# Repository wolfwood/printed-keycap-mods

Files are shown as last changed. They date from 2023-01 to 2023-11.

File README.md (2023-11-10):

# Print Keycaps That Feel Great
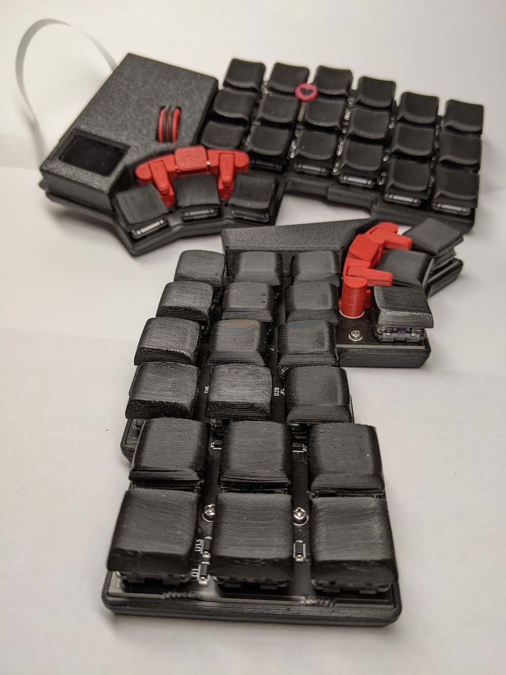
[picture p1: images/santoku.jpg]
Santoku Keyboard from Gestalt Input


This code modifies and positions open source, 3D printable key caps, such as Chicago Steno, for printing, using Lev Popov's suggestions for FDM printing keycaps in [the LPX repo](https://github.com/levpopov/LPX) and in [his printables for Chicago Steno](https://www.printables.com/model/158865-chicago-steno-low-profile-keycaps-kailh-choc).

## Modify Keycaps to Fit Around Trackpoint
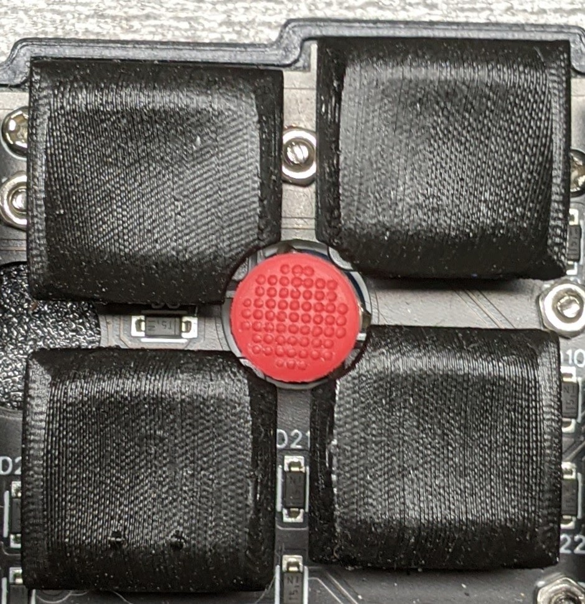
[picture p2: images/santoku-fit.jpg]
Chicago Steno around a Santoku trackpoint


This code also takes keycaps and cuts notches to make room for a trackpoint's rubber dome. No need to grind them down. It does this for the Santoku keyboard (pictured above), a tryadactyl with cylindrical placement, or ortholinear keyboards with MX or choc spacing. However, it can be easily modified to accommodate any keyboard layout.

### Placement
Two trackpoint placements are supported. The upper left corner of the home key, "index" or *index=true*, and the upper right corner of the home key, "middle" or *index=false*.

## Stupid Stem Tricks
For non-SCAD keycaps we can easily remove the stem using a `difference()` and replace it with whatever we like. This opens several possibilities. For SCAD keycaps we can likely tweak the source, or pass appropriate parameters.

### MX Stem Swap
The LPxMX profile is a choc keycap on an MX stem from @rsheldiii's [keyV2 library](https://github.com/rsheldiii/KeyV2.git) which was designed to be amenable to FDM printing.

### Stem Offsets
For dactyls using a typical cylindrical column placement, there is no issue with the keyswitches colliding. However, if we try to have a convex portion of our column (such as for the number row) the keycaps may be spaced far enough apart that the switches below would collide. Using an offset stem allows us to pack keycaps more tightly, while spacing the switches far enough apart that they don't intersect.

Currently only implemented for LPX.

# Profiles
### [LPX](https://github.com/levpopov/LPX)
No unmodified keycap is generated. Use [the source *.stl* file](https://github.com/levpopov/LPX/blob/main/LPX.stl).

Since LPX is a symmetrical, non-sculpted profile, right now only two trackpoint-modded keycaps are generated. Support for a homing key could be added.

### [Chicago Steno](https://github.com/pseudoku/PseudoMakeMeKeyCapProfiles)
A full set of keycaps can be rendered for printing.

For trackpoint use, an array of 4 keycaps is rendered (or optionally, files for individual keycaps), with the appropriate notches depending on *index* or *middle* placement. The keycaps are R3 homing, R3 and two R2s (near and far).

Chicago Steno from @pseudoku is made available under the GPL v3 and the optional (off by default) prerenders from @levpopov are CC BY-NC-SA 4.0.

# Usage
This repository relies on submodules to include keycaps where possible. Either clone it with the command `git clone --recurse-submodules --remote-submodules` to automatically fetch submodules, or run `git submodule update --init --recursive` in an already cloned repo before using.

Keycaps can be rendered using `make`. first edit `settings.scad` to set the keyboard, and optionally the grid spacing (only used by Chicago Steno for now). If run without arguments, `make` will render all profiles and positions for a given board. To save render time you can invoke a specific target such as `make lpx` or `make cs-middle`. A set of unmodified Chicago Steno keycaps can be generated with `make cs`. The targets `cs-middle-solo` and `cs-index-solo` generate modified keycaps in individual *.stl*s rather than arrays.

I strongly recommend downloading [a development snapshot of OpenSCAD](https://openscad.org/downloads.html#snapshots) and replacing the `OPENSCAD=openscad` line at the begining of the Makefile with the path to the downloaded build (don't forget to `chmod +x` it first, if using an AppImage), so that you can enable the `manifold` feature. I currently use `OPENSCAD=$(HOME)/downloads/OpenSCAD-2023.11.08.ai16933-x86_64.AppImage --enable=manifold --enable=predictible-output` (predictible-output will probably be slower, but it's useful for detecting changes).

# FDM Printing Suggestions
Parts are positioned with a 45 degree Y and Z rotation. These recommendations come from @levpopov. The Y rotation produces a smoother surface than printing flat. The Z rotation slows the print head and gets maximum cooling on the top surface.

If using a keycap array *.stl*, split the model to objects in your slicer, then enable *complete individual objects*.

The main issue I've had has been with the bottom edge of the keycap partially or full detaching during the print. The support tweaks are meant to address this issue, along with the model modifications to flatten the edges the keycap rests on while printing.

  - *layer height* - On the Prusa MK3S I used 0.1 mm. 0.07 mm is doable but arguably feels worse. 0.15 is acceptable and definitely where you should start your testing before trying to print multiple keycaps. On the Prusa MK4 I was able to use .05 mm with a brim which produced a very smooth top surface, but also a rough patch on one edge.
  - *0% infill* - This helps with surface smoothness. also faster.
  - *enable supports* - This thing is gonna tip over if you don't support it! I have preferred to use traditional supports. Tree supports are definitely not effective without a brim; the whole model benefits from a solid support structure. As of prusaslice 2.6, the default is support style is snug, which applies the following by default.
	- *Top contact Z distance* = 0.10 - get supports closer to the part
    - *Pattern spacing* = 1.5 - more supportive
  - *Complete individual objects* - prints parts one at a time so there isn't stringing between keycaps ruining the top surface. you also need to split models with multiple keycaps, if using.

# SLA Printing Suggestions
??? Someone with a resin printer please tell us.

# Suggestions Welcome!
Please open an issue to request support for new keycaps, new keyboards, flexibility in selecting row variants, etc. I'd like to expand this tool to accommodate as many uses as possible.

# TODO
  - [x] fix orientation of 'from source' CS keycaps
  - [x] check if LPX needs 2 different notches now that santoku offset is corrected
  - [ ] reorg related keycap code into directories
  - [ ] means to specify arbitrary arrays of keycaps (in settings/from render command)
    - [ ] split array generation off from main keycap files (can be generic? or per-profile?)
  - [x] means to generate individual trackpoint notched keycaps, not in an array
    - [x] communicate trackpoint notch location in a more clear and universal manner
  - [ ] way to add sprues to keycap arrays for commercial 3D printing? what about shrinkage?
  - [ ] stem mods, such as integrated tilters
	- [x] LPxMX
    - [x] LPX-offset
    - [ ] CS-MX
    - [ ] longer LPX stem for damper?
  - [ ] try out more keycaps from https://github.com/namnlos-io/choc_keycaps
  - [ ] https://github.com/madebyperce/shelby-min-mx-keycaps LPxMX alternative?
  - [ ] support more keycaps from keyV2? rewrite this code a branch of keyV2?
  - [ ] CS T1S
  - [ ] bigger homing dots?
  - [ ] makefile rules to fetch submodules if missing

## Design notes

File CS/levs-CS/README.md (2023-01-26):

# Chicago Steno *.stl*s

[Chicago Steno models](https://github.com/pseudoku/PseudoMakeMeKeyCapProfiles) by way of Lev Popov's [guide for FDM printed keycaps](https://www.printables.com/model/158865-chicago-steno-low-profile-ergo-keycaps).

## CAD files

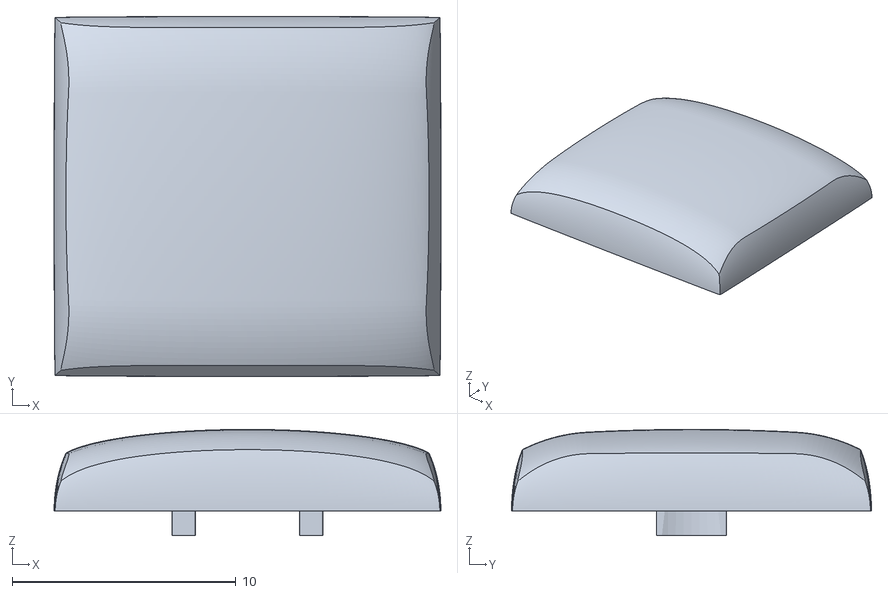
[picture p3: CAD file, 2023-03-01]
CS/levs-CS/convex-1u-for-thumbs-or-inner-index-column.stl
17.3 x 16.1 x 4.75

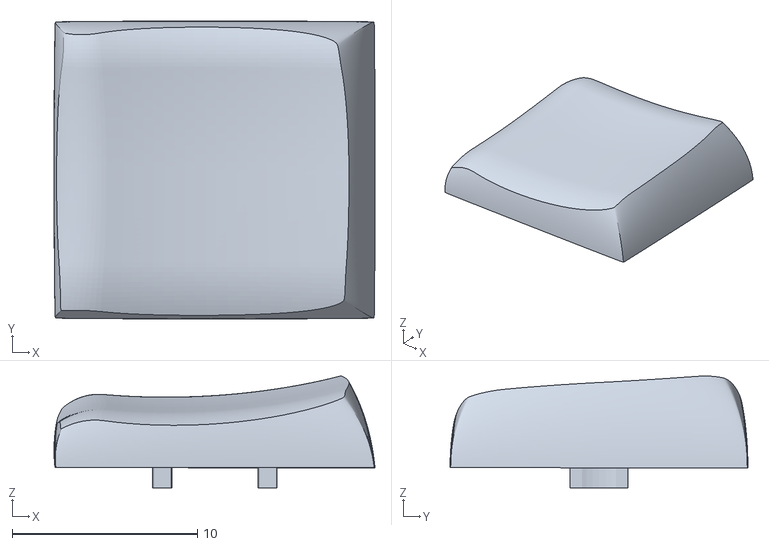
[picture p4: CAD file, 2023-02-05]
CS/levs-CS/thumb-1u.stl
17.4 x 16.1 x 6.05

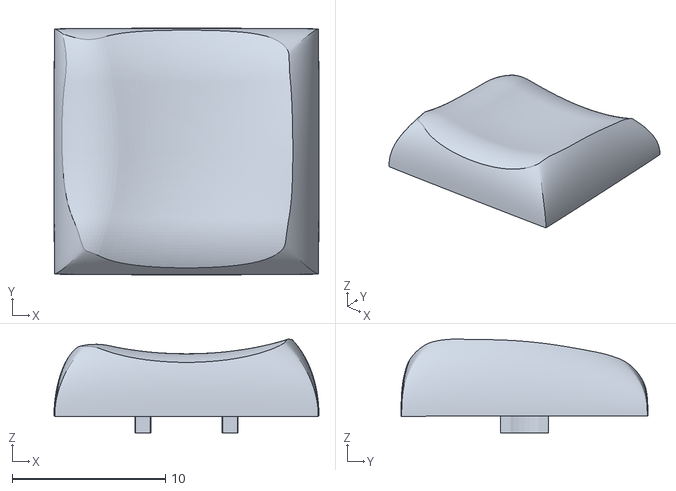
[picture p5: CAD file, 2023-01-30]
CS/levs-CS/r2r4L-side-columns.stl
17.3 x 16.1 x 6.12

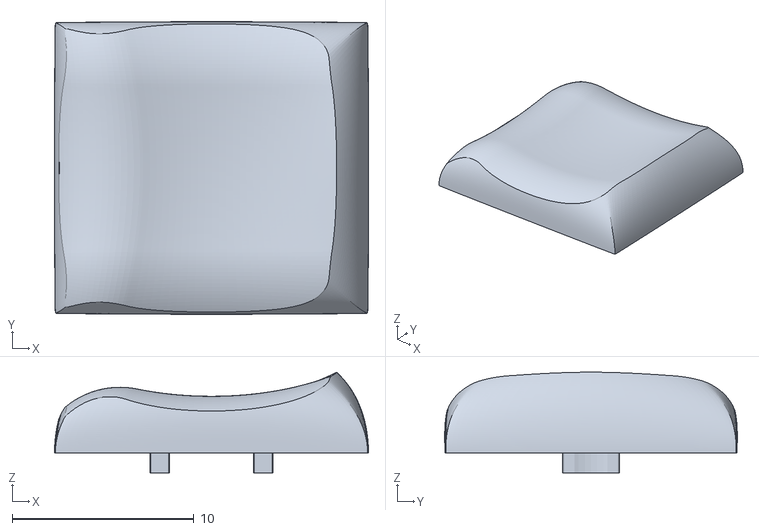
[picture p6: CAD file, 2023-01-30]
CS/levs-CS/r3L-side-columns.stl
17.3 x 16.1 x 5.55

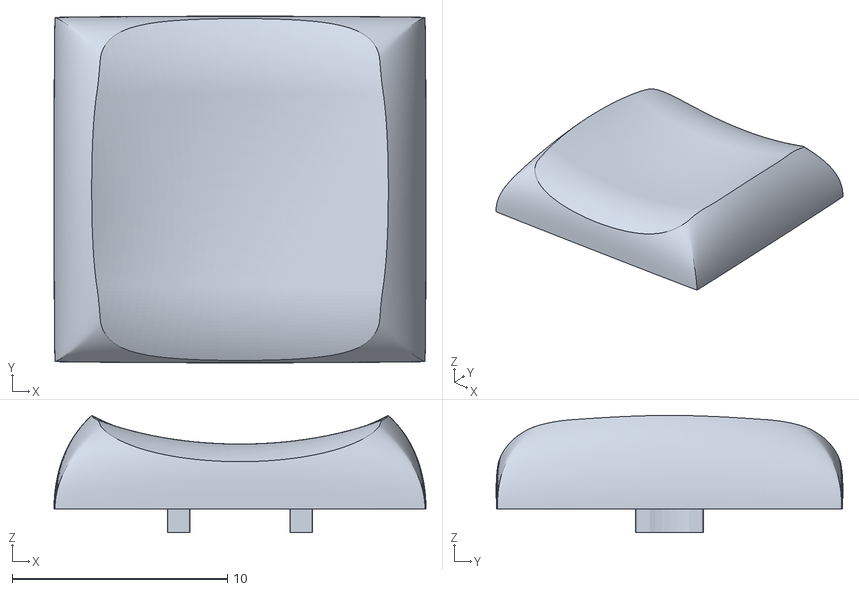
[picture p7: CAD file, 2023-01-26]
CS/levs-CS/r3-middle-row.stl
17.3 x 16.1 x 5.45

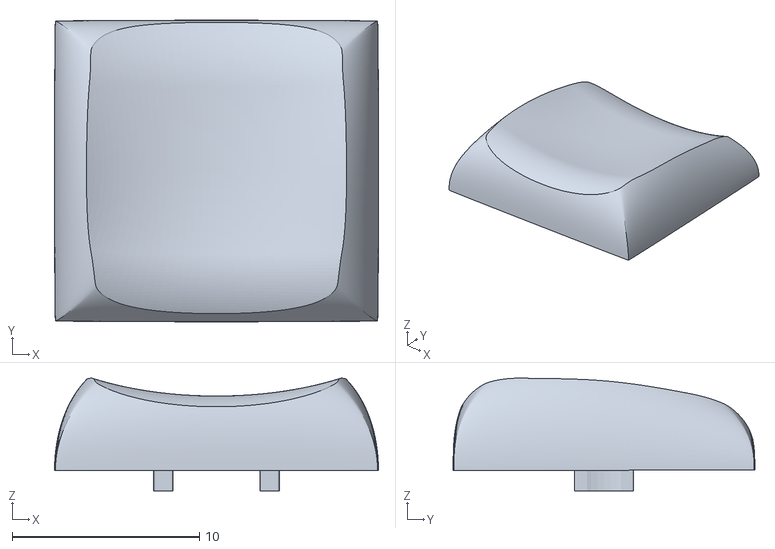
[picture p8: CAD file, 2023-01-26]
CS/levs-CS/r2r4-topbottom-rows.stl
17.3 x 16.1 x 6.02

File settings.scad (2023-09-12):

keyboard = "santoku";

grid_spacing = [54,66];
grid_stagger = true;


// original code was for a prusa MK3 with the print cooling fan duct on the right of the extruder
// MK4 has fan ducts on the left (and front)
fans_on_left=true;


// use a chamfered notch rather than a hole that accommodates the entire trackpoint cap
// chamfer makes a lot of polygons and can fail to preview / consume a lot of RAM and CPU when rendering
function tp_chamfer() = $preview ? false : true;

// less than .05 requires more than 8 GB of RAM if rendered in the gui
// not sure if there's a size that lets previews work
function tp_chamfer_steps() = .05;

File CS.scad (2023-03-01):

include <util.scad>;
include <trackpoint_notch.scad>;
include <settings.scad>;

use <CS-bindings/sculpted.scad>;
use <CS-bindings/thumb.scad>;
use <CS-bindings/convex.scad>;

prerendered=false;

module CS(type="R3") {
  if (prerendered) {
    CS_prerendered(type);
  } else {
    CS_from_source(type);
  }
}

module CS_from_source(type="R3") {
  $fn=60;

  if (type == "R3") {
    sculpted_key(type);
  } else if (type == "R3-homing") {
    sculpted_key("R3", homing=true);
  } else if (type == "R2") {
    mirror([0,1,0]) sculpted_key("R4");
  } else if (type == "R4") {
    sculpted_key(type);
  } else if (type == "R2L" || type == "R4R") {
    mirror([1,0,0]) thumb_key("R2L");
  } else if (type == "R3L" || type == "R3R") {
    // smoother feel if you don't print with the curved side at the top
    rotate([0,0,180]) thumb_key("R3L");
  } else if (type == "R4L" || type == "R2R") {
    // smoother feel if you don't print with the curved side at the top
    rotate([0,0,180]) thumb_key("R2L");
  } else if (type == "T1L") {
    // smoother feel if you don't print with the curved side at the top
    rotate([0,0,180]) thumb_key("T1");
  } else if (type == "T1R") {
    mirror([1,0,0]) thumb_key("T1");
  } else if (type == "R3x") {
    convex_key(type);
  } else {
    assert(false, str("unrecognized Chicago Steno keycap type: ", type));
  }
}

module CS_prerendered(type="R3") {
  if (type == "R3") {
    import("levs-CS/r3-middle-row.stl");
  } else if (type == "R3-homing") {
    import("levs-CS/r3-homing.stl");
  } else if (type == "R2") {
    rotate([0,0, 180]) import("levs-CS/r2r4-topbottom-rows.stl");
  } else if (type == "R4") {
    import("levs-CS/r2r4-topbottom-rows.stl");
  } else if (type == "R2L" || type == "R4R") {
    import("levs-CS/r2r4L-side-columns.stl");
  } else if (type == "R3L" || type == "R3R") {
    //rotate([0,0, 180])
      import("levs-CS/r3L-side-columns.stl");
  } else if (type == "R4L" || type == "R2R") {
    mirror([0,1,0]) import("levs-CS/r2r4L-side-columns.stl");
  } else if (type == "T1L") {
    rotate([0,0,180])
      mirror([1,0,0]) import("levs-CS/thumb-1u.stl");
  } else if (type == "T1R") {
    import("levs-CS/thumb-1u.stl");
  } else if (type == "R3x") {
    import("levs-CS/convex-1u-for-thumbs-or-inner-index-column.stl");
  } else {
    assert(false, str("unrecognized Chicago Steno keycap type: ", type));
  }
}

module printable(other=false) {
  difference(){
    rotate([0,0,other ? -45 : 135])
      rotate([0,(other ? 1 : -1)*45,0]) children();

    // nip off the edge so the keycap sticks better to the print bed
    h=5;
    cut_distance=4.9; // 5.6 is minimally invasive, but not as effective
    translate([0,0,-h/2 - cut_distance]) cube([40,40,h], center=true);
    rotate([0,90,-45])
      translate([0,0,-h/2 - cut_distance]) cube([40,40,h], center=true);
  }
}

index = false;

if (is_undef(keycap)) {
  let(x_spacing = is_list(grid_spacing) ? grid_spacing.x : grid_spacing, y_spacing = is_list(grid_spacing) ? grid_spacing.y : grid_spacing, stagger = is_undef(grid_stagger) ? 0 : grid_stagger ? y_spacing/2 : 0) {
    if (!index) { // middle
      if (is_undef(tpkey) || tpkey == "R3-homing") printable() trackpoint_notch(far=true) CS("R3-homing");
      if (is_undef(tpkey) || tpkey == "R2-near") translate(is_undef(tpkey) ? [0,y_spacing,0] : [0,0,0]) printable() trackpoint_notch(far=false) CS("R2");
      if (is_undef(tpkey) || tpkey == "R3") translate(is_undef(tpkey) ? [x_spacing,stagger,0] : [0,0,0]) printable(other=true) mirror([1,0,0]) trackpoint_notch(far=false, index=true) CS("R3");
      if (is_undef(tpkey) || tpkey == "R2-far") translate(is_undef(tpkey) ? [x_spacing,stagger+y_spacing,0] : [0,0,0]) printable(other=true) mirror([1,0,0]) trackpoint_notch(far=true, index=true) CS("R2");
    } else { // index
      if (is_undef(tpkey) || tpkey == "R3-homing") printable(true) mirror([1,0,0]) trackpoint_notch(far=false, index=true) CS("R3-homing");
      if (is_undef(tpkey) || tpkey == "R2-far") translate(is_undef(tpkey) ? [0,y_spacing,0] : [0,0,0]) printable(other=true) mirror([1,0,0]) trackpoint_notch(far=true, index=true) CS("R2");
      // if (is_undef(tpkey) || tpkey == "R3") translate([x_spacing,stagger,0] : [0,0,0]) printable() trackpoint_notch(far=true, index=false) CS("R3");
      //f (is_undef(tpkey) || tpkey == "R2-near") translate([x_spacing,stagger+y_spacing,0] : [0,0,0]) printable() trackpoint_notch(far=false, index=false) CS("R2");
       if (is_undef(tpkey) || tpkey == "R3") translate(is_undef(tpkey) ? [x_spacing,stagger,0] : [0,0,0]) printable(other=true) trackpoint_notch(far=true, index=false) rotate([0,0,180]) CS("R3L");
      if (is_undef(tpkey) || tpkey == "R2-near") translate(is_undef(tpkey) ? [x_spacing,stagger+y_spacing,0] : [0,0,0]) printable(other=true) trackpoint_notch(far=false, index=false) rotate([0,0,180]) CS("R2L");
    }
  }
} else {
  printable() CS(keycap);
}

debug_orientation=false;

if (debug_orientation) {
  grid_stagger = false;
  !let(x_spacing = is_list(grid_spacing) ? grid_spacing.x : grid_spacing, y_spacing = is_list(grid_spacing) ? grid_spacing.y : grid_spacing, stagger = is_undef(grid_stagger) ? 0 : grid_stagger ? y_spacing/2 : 0) {
    one = "T1L";
    two= "T1R";

    if (!is_undef(two)) CS_from_source(two);
    translate([0,y_spacing,0]) CS_from_source(one);
    if (!is_undef(two)) translate([x_spacing,stagger,0]) printable(two) CS_from_source(two);
    translate([x_spacing,stagger+y_spacing,0]) printable(one) CS_from_source(one);
    if (!is_undef(two)) translate([2*x_spacing,stagger,0]) printable(two) CS_prerendered(two);
    translate([2*x_spacing,stagger+y_spacing,0]) printable(one) CS_prerendered(one);
    if (!is_undef(two)) translate([3*x_spacing,stagger,0]) CS_prerendered(two);
    translate([3*x_spacing,stagger+y_spacing,0]) CS_prerendered(one);
  }
}

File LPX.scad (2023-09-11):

include <trackpoint_notch.scad>

module LPX() {
  translate([-1.605,-29.001/*-28.96958*/,-9.02 + 2.7644])
    rotate([48.5,0,90]) import("LPX/LPX.stl");
}

leg_cube = [7.2, 3.2, 6];
leg_cube_position = [0, 0, -leg_cube.z/2 + 1.3];

module LPX_legs() {
  intersection(){
    LPX();
    translate(leg_cube_position) cube(leg_cube, center=true);
  }
}
module LPX_shell() {
  difference() {
    LPX();
    translate(leg_cube_position-[0, 0, .001]) cube(leg_cube, center=true);
  }
}

module offset_LPX(pos=[0,1,0]) {
  if (pos == [0,0,0]) {
    LPX();
  } else {
    LPX_shell();
    translate(pos) LPX_legs();
  }
}


module printable() {
  rotate([0,0,-135]) rotate([-48.5,0,0]) rotate([0,0,-90]) children();
}

// LPX is symmetrical so the notch on lower right is the same as upper left
//  also its a very small footprint, so the far (small) notch keycaps don't need to be cut to fit around the trackpoint

far = false;
index = false;

printable() trackpoint_notch(far=far, index=index) LPX();

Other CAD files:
CS/levs-CS/r3-homing.stl
trackpoint_notch.scad
CS/CS-bindings/convex.scad
CS/CS-bindings/sculpted.scad
CS/CS-bindings/thumb.scad
CS/CS.scad
LPX/LPX.scad
LPX/MX.scad
util/chord.scad
util/logic.scad

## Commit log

2023-01-24 generates LPX .stls with notches cut out. Makefile to run render commands.
    [LPX.scad, santoku_spacing.scad, util.scad]
2023-01-26 add Chicago Steno and refactor notch cutter to make keyboard a parameter
    [CS.scad, LPX.scad, r2r4-topbottom-rows.stl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]
2023-01-26 option to stagger keycap array and allow spacing to be set independently for x and y
    [CS.scad, settings.scad]
2023-01-26 LPX middle and index are the same, unless we add a homing key.
2023-01-26 adjust grid spacing so CS arrays don't collide on a prusa mk3s
    [settings.scad]
2023-01-28 flatten the bottom edge so Chicago Steno is more printable
    [CS.scad]
2023-01-30 add more Chicago Steno key types
    [CS.scad, r2r4L-side-columns.stl, r3L-side-columns.stl]
2023-02-03 support other CS row profiles including R4, outer/inner column, and thumb.
    convex doesn't work from stl and so is omitted for now.
    [CS.scad, thumb-1u.stl]
2023-02-03 fix santoku hole placement
    [trackpoint_notch.scad]
2023-02-03 remove edges for FDM printing in a balanced way, ie on both sides not jus tthe one touching the print bed
    [CS.scad]
2023-02-05 use original source to generate Chicago Steno keycaps, rather than .stls.
    renders are faster and resulting .stls are smaller.
    [CS.scad, convex.scad, sculpted.scad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]
2023-02-09 add printing instructions to README
2023-02-09 allow CS to render single keycaps if passed a 'keycap' string
    [CS.scad]
2023-02-09 improve CS keycap profile options and positioning
    [CS.scad]
2023-02-09 factor out CS edge cut distance so tning is easier
    [CS.scad]
2023-02-09 gadget to inspect and debug keycap orientation
    [CS.scad]
2023-02-20 use pre-rendered CS keycaps until I validate the positioning / sculpt of the from_source version
    [CS.scad]
2023-02-22 consistent naming for homing key
    [CS.scad]
2023-02-22 fix filenames for prerender import
    [CS.scad]
2023-02-22 fix error message
    [sculpted.scad]
2023-03-01 correct CS keycap orientation
    [CS.scad, sculpted.scad]
2023-03-01 enhance CS debug_orientation
    [CS.scad]
2023-03-01 CS index trackpoint array uses outer column keycaps
    [CS.scad]
2023-03-01 use printable argument name
    [CS.scad]
2023-03-01 a method to automatically build .stls for individual trackpoint caps, instead of as an array.
    [CS.scad]
2023-03-01 dial down the trackpoint $fn to match everywhere else, and tighten the default diameter
    [trackpoint_notch.scad]
2023-03-01 update readme with new targets, printing instruction sources, todo checkmarks, dev snapshot recommendation.
2023-03-01 missing file
    [convex-1u-for-thumbs-or-inner-index-column.stl]
2023-03-07 cut trackpoint notch on cylindrical columns with lpx spacing
    [chord.scad, trackpoint_notch.scad]
2023-09-11 consolidate all the Chicago Steno stuff into one directory
    [CS.scad, LPX.scad, convex-1u-for-thumbs-or-inner-index-column.stl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]
2023-09-11 groundwork for modifiying LPX stem
    [LPX.scad]
2023-09-11 reorg LPX and introduce MX stemmed and offset variants
    [LPX.scad, MX.scad]
2023-09-11 prefer use to include, when possible
    [CS.scad, LPX.scad, trackpoint_notch.scad]
2023-09-11 adjust LPX spacing to reflect tighter Y-axis
    [trackpoint_notch.scad]
2023-09-11 not sure why my laptop doesn't need an xor() definition :thinking:
    [logic.scad, trackpoint_notch.scad]
2023-09-11 fix typo in trackpoint code
    [trackpoint_notch.scad]
2023-09-11 finish wiring up lpx-offset keycap rendering
    [LPX.scad]
2023-09-11 flatten the corners of the LPxMX stem to aid in printing, just like LPX
    [MX.scad]
2023-09-11 eliminate MX speed variant, all MX stems are the same height
    [MX.scad]
2023-09-11 add material to the inside lip of LPX-offset keycaps to indicate the amount of offset, so I can tell them apart
    [LPX.scad]
2023-09-11 tweak LPX centering
    [LPX.scad]
2023-09-11 add a version of LPX with one side rounded for lateral chords
    [LPX.scad]
2023-09-11 add a way to directly specify trackpoint position around a keycap
    [trackpoint_notch.scad]
2023-09-11 add 'lateral' to control whether CS index trackpoint keys use chording keys and clean up tp placement with $x and $y
    [CS.scad]
2023-09-11 add optional chamfered trackpoint notch, controlled by settings
    [settings.scad, trackpoint_notch.scad]
2023-09-12 add a setting to alter keycap placement depending on printer fan position
    [CS.scad, LPX.scad, settings.scad]
2023-09-12 remove mntion of speed switches from readme
2023-09-12 comment correction
    [trackpoint_notch.scad]
2023-11-09 fix CS printable trimming of edges
    [CS.scad]
2023-11-10 update printing advice
2024-11-02 move Pseudoku keycaps to includes directory
    [convex.scad, sculpted.scad, thumb.scad]
2024-11-02 fix CS orientation including offset and trackpoint keycaps
    [CS.scad]
